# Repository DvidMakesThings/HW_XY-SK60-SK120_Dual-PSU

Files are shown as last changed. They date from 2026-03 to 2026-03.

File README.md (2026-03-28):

# XY-SK60 / XY-SK120 Dual PSU Controller

**Open-source remote control and automation system for dual Sinilink XY-SK60/SK120 buck-boost power supplies — built around a Luckfox RV1106 SoC in a 10-inch 1U rack enclosure.**




---

## Table of Contents

- [Project Overview](#project-overview)
- [Hardware](#hardware)
  - [PSU Modules](#psu-modules-sinilink-xy-sk60--xy-sk120)
  - [Controller: Luckfox Pico Plus](#controller-luckfox-pico-plus-rv1106)
  - [Serial Interface & Wiring](#serial-interface--wiring)
  - [Enclosure](#enclosure)
  - [Bill of Materials](#bill-of-materials)
- [Software Architecture](#software-architecture)
- [Web UI](#web-ui)
  - [Outputs](#outputs)
  - [Protection](#protection)
  - [Settings](#settings)
  - [Sweep](#sweep)
  - [Datalogger](#datalogger)
  - [API Docs / SNMP Docs / System Info](#api-docs--snmp-docs--system-info)
- [REST API](#rest-api)
- [SNMP Agent](#snmp-agent)
- [Deployment](#deployment)
  - [Prerequisites](#prerequisites)
  - [Windows Deployment](#windows-deployment-pscp--plink)
  - [Linux / macOS Deployment](#linux--macos-deployment)
  - [Manual Deployment](#manual-deployment)
  - [Service Management](#service-management)
- [Configuration](#configuration)
- [Typical Use Cases](#typical-use-cases)
- [License](#license)
- [Contact](#contact)
- [Contributing](#contributing)

---

## Project Overview

This project turns two off-the-shelf Sinilink XY-SK60 or XY-SK120 buck-boost modules into a fully networked, rack-mounted lab power system. A Luckfox Pico Plus SBC (RV1106 SoC, running Linux) sits between the PSUs and the network, communicating with each PSU over Modbus RTU via dedicated UARTs and exposing a feature-rich control interface.

**What you get:**

| Capability | Detail |
|---|---|
| Web dashboard | Real-time V/I/P telemetry, output control, protection config, settings |
| Voltage sweep | Timed voltage sequences — define waypoints, upload, start/stop |
| Datalogger | Per-channel V/I/P time-series, live graph, CSV export |
| REST API | Full JSON API for scripting and automation |
| SNMP agent | SNMPv2c for integration with Zabbix, Nagios, LibreNMS, etc. |
| 10-inch 1U rack | 3D-printable enclosure, all files included |

---

## Hardware

### PSU Modules: Sinilink XY-SK60 / XY-SK120

The Sinilink XY-SK60 and XY-SK120 are synchronous buck-boost DC-DC converter modules with an onboard microcontroller, LCD display, and a serial (Modbus RTU) control port.

| Parameter | XY-SK60 | XY-SK120 |
|---|---|---|
| Input voltage | 8 – 60 V DC | 8 – 60 V DC |
| Output voltage | 1 – 60 V DC | 1 – 60 V DC |
| Max output current | 6 A | 12 A |
| Max output power | 60 W | 120 W |
| Conversion efficiency | up to 98% | up to 98% |
| Display | colour LCD | colour LCD |
| Serial interface | UART 115200 8N1 | UART 115200 8N1 |
| Control protocol | Modbus RTU (slave addr 1) | Modbus RTU (slave addr 1) |

Both variants expose identical register maps and are fully interchangeable in this system. The modules have a 6-pin serial header exposing TX, RX, GND and 3.3 V.

The `doc/` folder contains the official SK60/SK120 user guide PDF with the full register map.

### Controller: Luckfox Pico Plus (RV1106)

The controller runs on a [Luckfox Pico Plus](https://www.luckfox.com/), a credit-card-sized Linux SBC based on the Rockchip RV1106 SoC.

| Parameter | Value |
|---|---|
| SoC | Rockchip RV1106 (ARM Cortex-A7, 1.2 GHz) |
| RAM | 64 MB DDR2 |
| Storage | 8 MB SPI NOR flash (runs Linux from flash) |
| OS | BusyBox-based Linux |
| Network | 100 Mbit Ethernet |
| UARTs used | ttyS3 (PSU-B), ttyS4 (PSU-A) |

Any Linux SBC with two free UARTs and Ethernet will work as a drop-in replacement (Raspberry Pi Zero 2, Orange Pi Zero, etc.). Only the UART device paths in `config.json` need adjustment.

### Serial Interface & Wiring

Each PSU communicates at **115200 baud, 8N1, Modbus RTU** on a dedicated UART. The controller reads all live registers in a single burst (30 registers from address 0x00) and writes individual registers for commands.

```
PSU-A  ──TX──►  RV1106 ttyS4 RX
       ◄─RX──   RV1106 ttyS4 TX
       ──GND─   GND
       ──5V─    5 V (optional, but the PSU exposes an 5V supply pin on the UART header, can be used for powering the SoC)

PSU-B  ──TX──►  RV1106 ttyS3 RX
       ◄─RX──   RV1106 ttyS3 TX
       ──GND─   GND
```

The UARTs operate at 3.3 V logic. No level shifting is needed between the Luckfox and the PSU serial headers. Each UART is a point-to-point connection (no RS-485 bus required).

**Register address map (key registers):**

| Address | Name | Scale | Access |
|---|---|---|---|
| 0x0000 | V_SET — voltage setpoint | ÷ 100 → V | R/W |
| 0x0001 | I_SET — current limit | ÷ 1000 → A | R/W |
| 0x0002 | VOUT — output voltage | ÷ 100 → V | RO |
| 0x0003 | IOUT — output current | ÷ 1000 → A | RO |
| 0x0004 | POWER — output power | ÷ 100 → W | RO |
| 0x0005 | UIN — input voltage | ÷ 100 → V | RO |
| 0x000D | T_IN — internal temp | ÷ 10 → °C | RO |
| 0x0012 | ONOFF — output enable | 1=ON, 0=OFF | R/W |
| 0x0011 | CVCC — CV/CC mode | 0=CV, 1=CC | RO |
| 0x0010 | PROTECT — protection flags | bitmask | RO |

The full register map is in `src/psu_controller/modbus_psu.py` and the PSU user guide.

### Enclosure

The system is built into a **10-inch, 1U rack enclosure** that is fully 3D printable.

<p align="center">
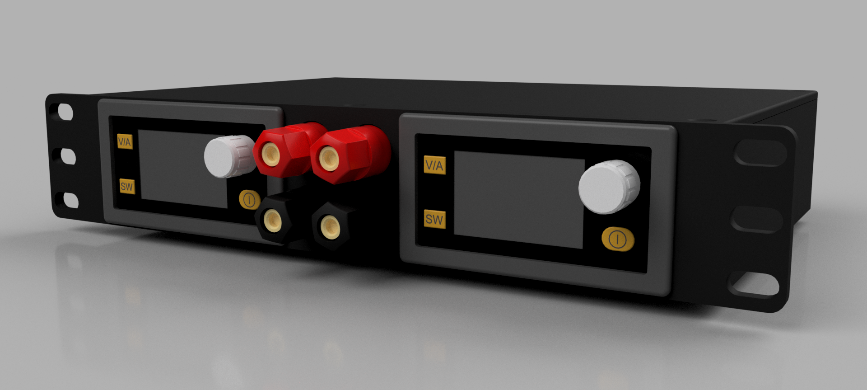
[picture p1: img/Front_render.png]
Front Render
  
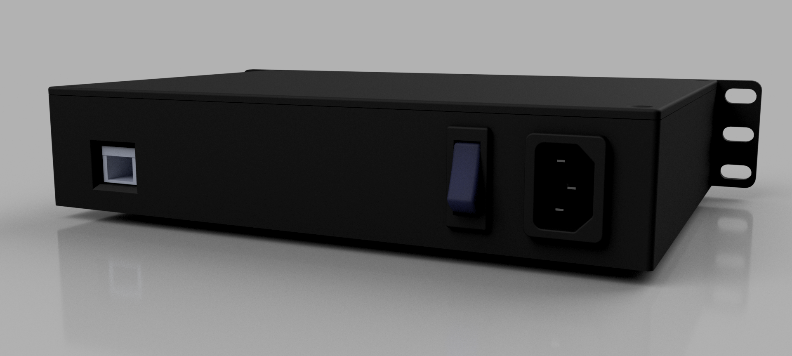
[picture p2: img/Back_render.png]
Back Render
  
</p>

<p align="center">
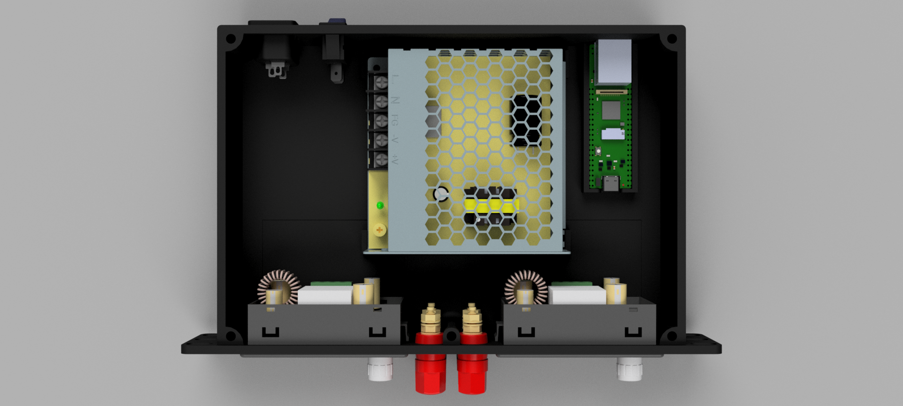
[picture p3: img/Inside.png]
Internal Layout
  
</p>

- **Form factor:** 1U × 10-inch rack (compatible with standard 10-inch patch panels and mini-racks)
- **3D files:** `3D files/` contains STEP models for the body, lid, and full assembly with internal components
- **Fastening:** designed for M3 hardware
- Both PSU modules mount inside the body, with the Luckfox mounted to the lid or rear panel

### Bill of Materials

Parts used in the reference build. Prices are approximate at time of purchase.

| Qty | Part | Unit Price | Link |
|---|---|---|---|
| 1 | Luckfox Pico Plus (RV1103) — SBC / controller | ~$20 | [luckfox.com](https://www.luckfox.com/EN-Luckfox-Pico-Plus) |
| 2 | Sinilink XY-SK120 60V/12A buck-boost module | ~$26 | [amazon.com](https://www.amazon.com/Converter-Voltage-Adjustable-Supply-Display/dp/B0D9H3Z637?th=1) |
| 1 | Mean Well LRS-75-12 — 12 V / 6 A PSU (logic power) | ~$14 | [amazon.com](https://a.co/d/09D2P6Ac) |
| 4 | Banana jack panel mounts (binding posts) | ~$2 each | [amazon.de](https://www.amazon.de/dp/B09D725WSX) |
| 1 | IEC 320 C14 panel-mount power inlet (4-pack) | ~$7/4 | [amazon.com](https://a.co/d/0aa4EqbB) |
| 1 | Snap-in rocker switch (5-pack) | ~$7/5 | [amazon.com](https://a.co/d/00OINL1y) |
| — | 14 AWG mains and DC wiring | — | — |

**Total reference build cost: ~$95** (excluding 3D printing filament, M3 hardware, and connectors)

> The XY-SK60 (6 A / 60 W) is a drop-in substitute for the XY-SK120 at lower cost (~$18) if you don't need 12 A output. Both are fully supported by this firmware.

---

## Software Architecture

The controller software runs as a single Python process under a BusyBox init.d service (`/etc/init.d/S99psucontroller`). All files install to `/opt/psu_controller/`.

```
psu_controller.py          ← main entry point, wires everything together
│
├── modbus_psu.py           ← Modbus RTU driver (one instance per PSU)
│    ├── read_all()          — bulk-reads 30 registers in one transaction
│    ├── set_voltage(v)      — writes REG_V_SET
│    ├── set_current(i)      — writes REG_I_SET
│    ├── set_output(on)      — writes REG_ONOFF
│    └── get_readings_cached() — returns last polled values (thread-safe)
│
├── web_server.py           ← single-threaded HTTP server (BaseHTTPRequestHandler)
│    ├── GET  /              — serves index.html
│    ├── GET  /app.js etc    — serves static web assets
│    ├── GET  /api/...       — JSON API read endpoints
│    └── POST /api/...       — JSON API command endpoints
│
├── sweep_manager.py        ← per-PSU timed voltage/output sequencer
│    ├── set_program()       — validates and stores waypoint list
│    ├── start()             — launches sweep thread
│    ├── stop()              — signals thread to stop
│    └── _run()              — 50 ms loop; applies waypoint actions on step change
│
├── datalogger.py           ← per-PSU time-series ring buffer logger
│    ├── start(interval_ms)  — launches logging thread
│    ├── stop()              — signals thread to stop
│    ├── get_data()          — returns samples as list of {t, v, i, p} dicts
│    └── get_csv()           — returns CSV string (time_ms, voltage_V, current_A, power_W)
│
├── snmp_agent.py           ← SNMPv2c agent (raw UDP socket, port 161)
│    └── exposes 28 OIDs per PSU channel (reads, settings, protection thresholds)
│
├── config.json             ← serial ports, baud rates, web/SNMP bind addresses
│
└── web/
     ├── index.html          ← single-page application shell
     ├── app.js              ← all UI logic (vanilla JS, no framework)
     └── style.css           ← all styles (CSS variables, grid, dark theme)
```

**Threading model:**
- Main thread: starts all services, then blocks
- Web server thread: one persistent thread handles all HTTP requests serially
- SNMP thread: one persistent thread handles all UDP datagrams serially
- PSU polling thread (×2): each `ModbusPSU` instance runs its own background thread that continuously polls registers and caches the result
- Sweep thread (×2, on demand): one thread per PSU when a sweep is running
- Datalogger thread (×2, on demand): one thread per PSU when logging is active

All shared state is protected by `threading.Lock()`. The web server never touches serial hardware directly — it reads from caches and dispatches commands to the PSU driver.

---

## Web UI

Access the web interface at `http://[DEVICE_IP]:8080/`. The UI is a single-page application with no external dependencies. All pages share a persistent sidebar for navigation and datalogger status.

### Outputs

<p align="center">
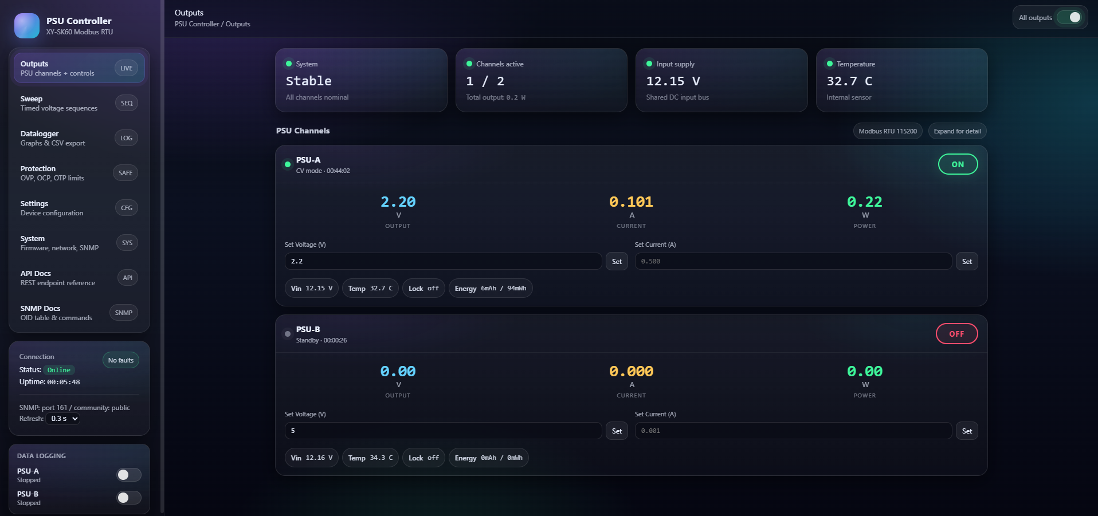
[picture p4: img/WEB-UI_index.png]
Web UI Outputs
  
</p>

The default page shows both PSU channels side by side (or stacked on narrow displays). For each channel:

- **Live readings** (refreshed every 300 ms): output voltage, current, power — displayed in large, colour-coded digits
- **Output toggle button**: green ON / grey OFF; reflects actual hardware state
- **CV/CC indicator**: shows whether the PSU is operating in constant-voltage or constant-current mode
- **Uptime counter**: accumulated output-on time (H:MM:SS)
- **Set Voltage / Set Current inputs**: type a value and press Set (or Enter). Inputs use `type="text"` to preserve partial input during polling; the placeholder shows the current setpoint. Inputs are fully stable during refresh — focus, cursor position, and text selection are never disturbed by background polling.
- **Info chips**: input voltage, internal temperature, key lock state, accumulated energy (mAh / mWh), and protection alert if active

### Protection

Per-channel protection threshold configuration:

| Setting | Description |
|---|---|
| OVP | Over-Voltage Protection — shuts output if Vout exceeds threshold |
| OCP | Over-Current Protection — shuts output if Iout exceeds threshold |
| OPP | Over-Power Protection — shuts output if power exceeds threshold |
| OTP | Over-Temperature Protection — shuts output if temp exceeds threshold |
| LVP | Low-Voltage Protection — shuts output if Vin drops below threshold |
| OHP | Over-Hours Protection — shuts output after a set run time (H:MM) |
| OAH | Over Amp-Hours — shuts output after accumulated charge (mAh) |
| OWH | Over Watt-Hours — shuts output after accumulated energy (mWh) |

### Settings

Per-channel device settings: backlight level (0–5), auto-sleep timeout, key lock, beeper, temperature unit (°C/°F), MPPT solar mode, constant-power mode, battery-full cutoff current, preset data group selection, power-on output state, temperature sensor calibration offsets, and factory reset.

### Sweep

The sweep function lets you define and execute a timed voltage/output sequence on each PSU independently. This is useful for automated test sequences, burn-in profiles, ramp testing, and similar applications.

<p align="center">
  <img src="img\WEB-UI_Sweep.png" alt="Sweep" "/>
</p>

**How waypoints work:**

Each waypoint specifies an **elapsed time from sweep start** and one or both of:
- **Voltage** — set the output voltage to this value at this timestamp
- **Output state** — turn output ON or OFF at this timestamp

Waypoints are sorted by time and executed in order. The sweep runs at 50 ms resolution. When the last waypoint time is reached, the sweep ends automatically and the PSU holds its last-programmed voltage.

**Example sequence** (ramp + test + off):

| Time | Action |
|---|---|
| 0 ms | Enable output, set 0.0 V |
| 500 ms | Set 5.0 V |
| 2000 ms | Set 12.0 V |
| 5000 ms | Set 12.0 V (hold) |
| 8000 ms | Set 5.0 V |
| 10000 ms | Disable output |

**UI workflow:**
1. Click `+ Voltage` or `+ Enable Output` / `+ Disable Output` to add waypoints
2. Set the elapsed time (ms) for each waypoint
3. Press **Save Program** — uploads the program to the controller
4. Press **Start** to begin execution; **Stop** to abort at any time
5. Status shows elapsed time and current step while running

Both PSUs maintain independent programs. Sweeps on both PSUs can run simultaneously.

### Datalogger

The datalogger records voltage, current, and power samples from each PSU at a configurable interval (minimum 100 ms, default 500 ms). Up to 10,000 samples are stored in memory per channel in a ring buffer (oldest are dropped when full).

<p align="center">
  <img src="img\WEB-UI_Datalogger.png" alt="Datalogger" "/>
</p>

**Enabling logging:**
- Toggle the **LOG** switch in the sidebar for each PSU channel
- The switch can also be controlled via the REST API

**Datalogger page:**
- Two-column layout with PSU-A on the left, PSU-B on the right
- Each column has two canvas charts: voltage (cyan) and current (yellow)
- Y axes auto-scale to the data range
- X axis shows absolute elapsed time from first sample

**Interactive hover:**
Move the mouse over any chart. When the cursor is within 20 px of the plotted curve, the chart shows:
- A dashed vertical crosshair at the nearest sample
- A filled dot on the curve
- A tooltip with the exact value and elapsed time (e.g. `3.284V  @1.23s`)

**CSV export:**
- Click **Download CSV** to download the log for each PSU
- Or `GET /api/datalog/{id}/csv` via the API
- Columns: `time_ms, voltage_V, current_A, power_W`
- Compatible with Excel, pandas, MATLAB, gnuplot, etc.

### API Docs / SNMP Docs / System Info

The last three sidebar items are reference panels built into the UI:

- **API Docs** — full REST endpoint reference with live base URL, payload examples, and curl commands (the device IP is substituted automatically)
- **SNMP Docs** — full OID table (28 columns, 2 rows), type/scale/access info, and a complete set of copy-pasteable snmpget/snmpset commands with the device IP pre-filled
- **System Info** — firmware version, serial port assignments, SNMP configuration, and network details

---

## REST API

Full reference: [API.md](API.md)

**Base URL:** `http://[DEVICE_IP]:8080/api/`

All GET endpoints return JSON. All POST endpoints accept a JSON body and return `{"success": true}` or `{"success": false, "error": "..."}`. CORS is open (`*`), so the API can be called from browser scripts on any origin.

**Quick reference:**

| Method | Endpoint | Purpose |
|---|---|---|
| GET | `/api/status` | All PSU data in one call |
| GET | `/api/psu/{id}/readings` | Live V/I/P/Vin/Temp readings |
| POST | `/api/psu/{id}/output` | Enable/disable output |
| POST | `/api/psu/{id}/voltage` | Set voltage setpoint |
| POST | `/api/psu/{id}/current` | Set current limit |
| GET | `/api/sweep/{id}` | Sweep program and run status |
| POST | `/api/sweep/{id}/set` | Upload a sweep program |
| POST | `/api/sweep/{id}/start` | Start sweep execution |
| POST | `/api/sweep/{id}/stop` | Stop sweep |
| GET | `/api/datalog/{id}` | Logged samples (JSON) |
| GET | `/api/datalog/{id}/csv` | Logged samples (CSV download) |
| POST | `/api/datalog/{id}/start` | Start logging |
| POST | `/api/datalog/{id}/stop` | Stop logging |
| POST | `/api/datalog/{id}/clear` | Clear buffer |

PSU IDs are `a` and `b`.

**Scripting example (bash):**
```bash
BASE=http://192.168.0.190:8080/api
# Ramp PSU-A to 12 V, enable output, log for 10 s, download CSV
curl -sX POST -H 'Content-Type:application/json' -d '{"voltage":12.0}' $BASE/psu/a/voltage
curl -sX POST -H 'Content-Type:application/json' -d '{"enabled":true}'  $BASE/psu/a/output
curl -sX POST -H 'Content-Type:application/json' -d '{"interval_ms":200}' $BASE/datalog/a/start
sleep 10
curl -sX POST $BASE/datalog/a/stop
curl -o psu_a.csv $BASE/datalog/a/csv
```

**Python example:**
```python
import requests, time

BASE = 'http://192.168.0.190:8080/api'

# Set voltage and enable output
requests.post(f'{BASE}/psu/a/voltage', json={'voltage': 5.0})
requests.post(f'{BASE}/psu/a/output',  json={'enabled': True})

# Poll readings
r = requests.get(f'{BASE}/psu/a/readings').json()
print(f"Vout={r['v_out']:.3f} V  Iout={r['i_out']:.3f} A  P={r['power']:.2f} W")

# Upload and run a sweep
points = [
    {'time_ms': 0,     'voltage': 0.0},
    {'time_ms': 1000,  'voltage': 5.0},
    {'time_ms': 3000,  'voltage': 12.0},
    {'time_ms': 6000,  'voltage': 3.3},
    {'time_ms': 8000,  'output': False},
]
requests.post(f'{BASE}/sweep/a/set',   json={'points': points})
requests.post(f'{BASE}/sweep/a/start', json={})
```

---

## SNMP Agent

Full reference: [SNMP.md](SNMP.md)

The controller runs a built-in SNMPv2c agent on **UDP port 161**. It exposes 28 OID columns per PSU channel (56 leaf OIDs total) covering all live readings, settings, and protection thresholds. Both GET and SET are supported; writable OIDs accept raw integer values scaled by the documented factor.

**Configuration:**
- Read community: `public`
- Write community: `private`
- Base OID: `1.3.6.1.4.1.99999.1`
- Rows: 1 = PSU-A, 2 = PSU-B
- Supports: GET, GETNEXT, GETBULK, SET

**Quick examples:**
```bash
# Read output voltage of PSU-A (raw x100, e.g. 1250 = 12.50 V)
snmpget -v2c -c public 192.168.0.190 1.3.6.1.4.1.99999.1.2.1.5.1

# Set PSU-B voltage to 5.00 V
snmpset -v2c -c private 192.168.0.190 1.3.6.1.4.1.99999.1.2.1.3.2 i 500

# Walk all parameters for all channels
snmpwalk -v2c -c public 192.168.0.190 1.3.6.1.4.1.99999.1.2

# Bulk-get all 28 OID columns for PSU-A in one packet
snmpbulkget -v2c -c public -Cr28 192.168.0.190 1.3.6.1.4.1.99999.1.2.1.0.1
```

For Zabbix integration, add the device as an SNMP host with community `public` and create items using the OIDs from [SNMP.md](SNMP.md). The raw integer values require the divisor applied in the Zabbix preprocessing step (multiply by 0.01 for x100-scaled voltage, 0.001 for x1000-scaled current, etc.).

---

## Deployment

### Prerequisites

The PSU modules and controller must be physically assembled and wired (see [Serial Interface & Wiring](#serial-interface--wiring)). The Luckfox device must be on the network and reachable by SSH.

Default device credentials: `root` / `luckfox`

### Windows Deployment (pscp + plink)

Requires [PuTTY tools](https://www.chiark.greenend.org.uk/~sgtatham/putty/latest.html) (`pscp.exe`, `plink.exe`) in your PATH.

```cmd
# Auto-detect device and deploy with default password
setup_psu_server.bat

# Specify IP
setup_psu_server.bat 192.168.0.190

# Specify IP and custom password
setup_psu_server.bat 192.168.0.190 mypassword
```

The script:
1. Uploads all files in `src/psu_controller/` to `/opt/psu_controller/` on the device
2. Installs the init.d service (`/etc/init.d/S99psucontroller`)
3. Starts the service

### Linux / macOS Deployment

Requires `sshpass` and `scp`.

```bash
# Install sshpass if needed
sudo apt install sshpass   # Debian/Ubuntu
brew install hudochenkov/sshpass/sshpass  # macOS

# Deploy
bash setup_psu_server.sh
bash setup_psu_server.sh 192.168.0.190
bash setup_psu_server.sh 192.168.0.190 mypassword
```

### Manual Deployment

If you prefer to deploy manually or from a CI pipeline:

```bash
DEVICE=192.168.0.190
PASS=luckfox

# Upload Python files
for f in psu_controller.py modbus_psu.py web_server.py snmp_agent.py \
          sweep_manager.py datalogger.py config.json; do
    sshpass -p $PASS scp src/psu_controller/$f root@$DEVICE:/opt/psu_controller/$f
done

# Upload web assets
for f in index.html style.css app.js; do
    sshpass -p $PASS scp src/psu_controller/web/$f root@$DEVICE:/opt/psu_controller/web/$f
done

# Upload service script
sshpass -p $PASS scp src/psu_controller/S99psucontroller root@$DEVICE:/etc/init.d/
sshpass -p $PASS ssh root@$DEVICE "chmod +x /etc/init.d/S99psucontroller"

# Start service
sshpass -p $PASS ssh root@$DEVICE "sh /etc/init.d/S99psucontroller restart"
```

### Service Management

The controller runs as a BusyBox init.d service (the Luckfox does **not** use systemd).

```bash
# Restart service (e.g. after a config change or file upload)
plink -batch -pw luckfox root@192.168.0.190 "sh /etc/init.d/S99psucontroller restart"

# Stop / start
plink -batch -pw luckfox root@192.168.0.190 "sh /etc/init.d/S99psucontroller stop"
plink -batch -pw luckfox root@192.168.0.190 "sh /etc/init.d/S99psucontroller start"

# View live log
plink -batch -pw luckfox root@192.168.0.190 "tail -f /var/log/psu_controller.log"
```

The web server and SNMP agent start automatically on boot. No manual start is needed after initial deployment.

---

## Configuration

`src/psu_controller/config.json` is the single configuration file. It is copied to `/opt/psu_controller/config.json` on the device.

```json
{
    "psus": {
        "a": {
            "port": "/dev/ttyS4",
            "name": "PSU-A",
            "baudrate": 115200,
            "address": 1
        },
        "b": {
            "port": "/dev/ttyS3",
            "name": "PSU-B",
            "baudrate": 115200,
            "address": 1
        }
    },
    "web": {
        "host": "0.0.0.0",
        "port": 8080
    },
    "snmp": {
        "host": "0.0.0.0",
        "port": 161,
        "community": "public",
        "write_community": "private"
    }
}
```

**Key fields:**

| Field | Description |
|---|---|
| `psus.{id}.port` | Serial device node for this PSU |
| `psus.{id}.address` | Modbus slave address (default 1, set on PSU) |
| `psus.{id}.baudrate` | Must match PSU baud setting (default 115200) |
| `psus.{id}.name` | Display name shown in UI |
| `web.port` | HTTP server port (default 8080) |
| `snmp.community` | Read community string |
| `snmp.write_community` | Write community string |

To add a third PSU (if using a controller with a third UART), add a `"c"` key under `psus` with the appropriate port.

After editing `config.json`, upload it and restart the service.

---

## Typical Use Cases

**Automated test bench** — Upload a sweep program via the API before each test run. Start the sweep from a test script, poll `/api/psu/{id}/readings` to measure DUT response, stop and download the log as CSV when done. Fully scriptable with any language that can make HTTP requests.

**Battery characterisation** — Enable the datalogger at 100–200 ms intervals while running a discharge sweep. Export the CSV and plot V/I vs. time in Python/MATLAB to extract capacity, internal resistance, and discharge curves.

**Solar MPPT lab testing** — Use MPPT mode on one PSU to simulate a solar panel source, and the other PSU in CC mode as a programmable load. Run both sweeps simultaneously and log both channels to correlate the waveforms.

**Zabbix / Nagios monitoring** — Add the device as an SNMP v2c host. Monitor output voltage, current, temperature, and protection status. Alert on protection events (psuProtectStatus != 0) or overcurrent conditions.

**Burn-in testing** — Define a long-duration sweep with output on/off cycles and varying voltages. The sweep runs unattended and ends automatically; no poll loop required.

---

## License
### Software Components
This project's software is licensed under the **GNU Affero General Public License v3.0 (AGPL-3.0)**.
See the [Software License](LICENSE-AGPL) file for details.

#### What AGPL-3.0 means:

- ✅ **You can** freely use, modify, and distribute this software
- ✅ **You can** use this project for personal, educational, or internal purposes
- ✅ **You can** contribute improvements back to this project

- ⚠️ **You must** share any modifications you make if you distribute the software
- ⚠️ **You must** release the source code if you run a modified version on a server that others interact with
- ⚠️ **You must** keep all copyright notices intact

- ❌ **You cannot** incorporate this code into proprietary software without sharing your source code
- ❌ **You cannot** use this project in a commercial product without either complying with AGPL or obtaining a different license

### Hardware Components
Hardware designs, schematics, and related documentation are licensed under the **Creative Commons Attribution-NonCommercial-ShareAlike 4.0 International License (CC BY-NC-SA 4.0)**. See the [Hardware License](LICENSE-CC-BY-NC-SA) file for details.

#### What CC BY-NC-SA 4.0 means:

- ✅ **You can** study, modify, and distribute the hardware designs
- ✅ **You can** create derivative works for personal, educational, or non-commercial use
- ✅ **You can** build this project for your own personal use

- ⚠️ **You must** give appropriate credit and indicate if changes were made
- ⚠️ **You must** share any modifications under the same license terms
- ⚠️ **You must** include the original license and copyright notices

- ❌ **You cannot** use the designs for commercial purposes without explicit permission
- ❌ **You cannot** manufacture and sell products based on these designs without a commercial license
- ❌ **You cannot** create closed-source derivatives for commercial purposes
- ❌ **You cannot** use the designer's trademarks without permission

### Commercial & Enterprise Use

Commercial use of this project is prohibited without obtaining a separate commercial license. If you are interested in:

- Manufacturing and selling products based on these designs
- Incorporating these designs into commercial products
- Any other commercial applications

Please contact me through any of the channels listed in the [Contact](#contact) section to discuss commercial licensing arrangements. Commercial licenses are available with reasonable terms to support ongoing development.

## Contact

For questions or feedback:
- **Email:** [dvidmakesthings@gmail.com](mailto:dvidmakesthings@gmail.com)
- **GitHub:** [DvidMakesThings](https://github.com/DvidMakesThings)

## Contributing

Contributions are welcome! As this is an early-stage project, please reach out before 
making substantial changes:

1. Fork the repository
2. Create a feature branch (`git checkout -b feature/concept`)
3. Commit your changes (`git commit -m 'Add concept'`)
4. Push to the branch (`git push origin feature/concept`)
5. Open a Pull Request with a detailed description

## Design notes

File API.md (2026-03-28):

# REST API Reference

This document describes the full REST API exposed by the Dual PSU Controller.

**Base URL:** `http://[DEVICE_IP]:8080/api/`
**PSU IDs:** `a` (PSU-A) and `b` (PSU-B)
**Content-Type:** All POST requests must include `Content-Type: application/json`
**CORS:** `Access-Control-Allow-Origin: *` — the API is accessible from any browser origin

---

## Response Format

**GET endpoints** return a JSON object with the requested data.

**POST endpoints** always return:
```json
{ "success": true }
```
or on failure:
```json
{ "success": false, "error": "Human-readable error message" }
```

---

## Status Endpoints

### `GET /api/status`
Full status object for all connected PSUs. Combines readings, settings, and protection data in a single call. Useful for dashboards that need everything at once.

**Response:**
```json
{
  "a": {
    "name": "PSU-A",
    "v_set": 12.50,
    "i_set": 2.000,
    "v_out": 12.48,
    "i_out": 0.312,
    "power": 3.89,
    "v_in": 24.10,
    "ah": 142,
    "wh": 1730,
    "out_hours": 0,
    "out_mins": 12,
    "out_secs": 34,
    "temp_int": 31.8,
    "temp_ext": -1.0,
    "lock": 0,
    "protect": 0,
    "cvcc": 0,
    "output_on": true,
    "backlight": 3,
    "sleep": 0,
    "beeper": 1,
    "f_c": 0,
    "model": 6000,
    "firmware": 130,
    "protection": {
      "ovp": 62.0, "ocp": 6.100, "opp": 360.0,
      "otp": 80.0, "lvp": 10.0,
      "ohp_h": 0, "ohp_m": 0, "oah": 0, "owh": 0,
      "power_on_init": false
    }
  },
  "b": { "..." }
}
```

### `GET /api/psu/{id}`
Full status for a single PSU. Same structure as one entry in `/api/status`.

```bash
curl http://192.168.0.190:8080/api/psu/a
```

### `GET /api/psu/{id}/readings`
Live measurements only. Polled at the PSU background thread rate (~200 ms cycle).

**Response:**
```json
{
  "v_out": 12.48,
  "i_out": 0.312,
  "power": 3.89,
  "v_in": 24.10,
  "v_set": 12.50,
  "i_set": 2.000,
  "ah": 142,
  "wh": 1730,
  "out_hours": 0,
  "out_mins": 12,
  "out_secs": 34,
  "temp_int": 31.8,
  "temp_ext": -1.0,
  "cvcc": 0,
  "output_on": true,
  "protect": 0
}
```

`cvcc`: `0` = constant-voltage mode, `1` = constant-current mode.
`protect`: protection status register bitmask; `0` = no active protection event.
`temp_ext`: `-1.0` indicates no external sensor connected.

```bash
curl http://192.168.0.190:8080/api/psu/a/readings
```

### `GET /api/psu/{id}/settings`
Device configuration settings.

**Response:**
```json
{
  "backlight": 3,
  "sleep": 0,
  "lock": 0,
  "beeper": 1,
  "f_c": 0,
  "model": 6000,
  "firmware": 130,
  "slave_addr": 1,
  "baudrate": 6
}
```

### `GET /api/psu/{id}/protection`
Protection thresholds and accumulated energy limits.

**Response:**
```json
{
  "ovp": 62.0,
  "ocp": 6.100,
  "opp": 360.0,
  "otp": 80.0,
  "lvp": 10.0,
  "ohp_h": 0,
  "ohp_m": 0,
  "oah": 0,
  "owh": 0,
  "power_on_init": false
}
```

### `GET /api/snmp`
SNMP agent configuration (community strings, port, base OID).

```bash
curl http://192.168.0.190:8080/api/snmp
```

---

## Control Endpoints

### `POST /api/psu/{id}/output`
Enable or disable the PSU output.

```json
{ "enabled": true }
```
```bash
curl -X POST -H 'Content-Type: application/json' \
     -d '{"enabled":true}' \
     http://192.168.0.190:8080/api/psu/a/output
```

### `POST /api/psu/{id}/voltage`
Set the output voltage setpoint in volts. The PSU enforces its own OVP limit.

```json
{ "voltage": 12.50 }
```
```bash
curl -X POST -H 'Content-Type: application/json' \
     -d '{"voltage":12.5}' \
     http://192.168.0.190:8080/api/psu/a/voltage
```

### `POST /api/psu/{id}/current`
Set the output current limit in amps.

```json
{ "current": 2.000 }
```

### `POST /api/psu/{id}/lock`
Lock or unlock the front panel keys (prevents physical button presses from changing settings).

```json
{ "locked": true }
```

### `POST /api/psu/{id}/backlight`
Set the LCD backlight level. `0` = off, `5` = maximum brightness.

```json
{ "level": 3 }
```

### `POST /api/psu/{id}/sleep`
Auto-sleep timeout in minutes. `0` disables auto-sleep.

```json
{ "minutes": 30 }
```

### `POST /api/psu/{id}/beeper`
Enable or disable the key press beeper.

```json
{ "enabled": false }
```

### `POST /api/psu/{id}/temp_unit`
Switch the temperature display between Celsius and Fahrenheit.

```json
{ "fahrenheit": true }
```

### `POST /api/psu/{id}/mppt`
Enable MPPT (Maximum Power Point Tracking) solar mode and/or set the input voltage threshold. In MPPT mode, the PSU regulates its input current to keep input voltage at or above the threshold, preventing source collapse.

```json
{ "enabled": true, "threshold": 18.0 }
```

### `POST /api/psu/{id}/cp`
Enable constant-power mode and/or set the power target in watts. The PSU adjusts current to maintain the specified output power.

```json
{ "enabled": true, "power": 25.0 }
```

### `POST /api/psu/{id}/btf`
Battery-full cutoff current threshold in amps. The output turns off automatically when output current drops below this value. Useful for CC/CV battery charging.

```json
{ "current": 0.100 }
```

### `POST /api/psu/{id}/data_group`
Select a preset data group (0–9). Each group stores independent V/I setpoints on the PSU.

```json
{ "group": 3 }
```

### `POST /api/psu/{id}/power_on_init`
Set whether the output is automatically enabled on PSU power-up.

```json
{ "output_on": true }
```

---

## Protection Endpoints

### `POST /api/psu/{id}/ovp`
Over-Voltage Protection threshold in volts. Output shuts off if Vout exceeds this value.

```json
{ "voltage": 62.0 }
```

### `POST /api/psu/{id}/ocp`
Over-Current Protection threshold in amps. Output shuts off if Iout exceeds this value.

```json
{ "current": 6.100 }
```

### `POST /api/psu/{id}/opp`
Over-Power Protection threshold in watts.

```json
{ "power": 360.0 }
```

### `POST /api/psu/{id}/otp`
Over-Temperature Protection threshold in °C. Output shuts off if the internal sensor exceeds this temperature.

```json
{ "temperature": 80.0 }
```

### `POST /api/psu/{id}/lvp`
Low-Voltage Protection threshold on the DC input (volts). Output shuts off if the input bus voltage drops below this level. Useful for protecting battery sources from deep discharge.

```json
{ "voltage": 10.0 }
```

### `POST /api/psu/{id}/ohp`
Over-Hours Protection. Output shuts off after this cumulative run time.

```json
{ "hours": 8, "minutes": 30 }
```

### `POST /api/psu/{id}/oah`
Over Amp-Hours Protection threshold in mAh. Output shuts off after this accumulated charge has been delivered.

```json
{ "mah": 5000 }
```

### `POST /api/psu/{id}/owh`
Over Watt-Hours Protection threshold in mWh. Output shuts off after this accumulated energy has been delivered.

```json
{ "mwh": 50000 }
```

### `POST /api/psu/{id}/temp_cal`
Apply a calibration offset in °C to the internal and/or external temperature sensors. Positive values increase the reported temperature; negative values decrease it.

```json
{ "internal": 0.5, "external": -1.2 }
```

### `POST /api/psu/{id}/factory_reset`
Reset all settings to factory defaults. This cannot be undone.

```json
{}
```
```bash
curl -X POST http://192.168.0.190:8080/api/psu/a/factory_reset
```

---

## Sweep Endpoints

The sweep system executes a timed sequence of voltage and/or output-state changes on a PSU. Each waypoint specifies an elapsed time (ms from sweep start) and at least one action (`voltage` and/or `output`). Waypoints are sorted by `time_ms` server-side and executed at 50 ms resolution. The sweep ends automatically after the last waypoint.

### `GET /api/sweep`
Sweep program and execution status for all PSUs.

**Response:**
```json
{
  "a": {
    "program": [
      { "time_ms": 0,     "voltage": 0.0 },
      { "time_ms": 500,   "output": true  },
      { "time_ms": 1000,  "voltage": 5.0  },
      { "time_ms": 5000,  "voltage": 12.0 },
      { "time_ms": 10000, "output": false }
    ],
    "status": {
      "running": true,
      "elapsed_ms": 3240,
      "current_step": 2
    }
  },
  "b": { "..." }
}
```

`current_step`: index (0-based) of the last applied waypoint. `-1` before any waypoint has been applied.

### `GET /api/sweep/{id}`
Sweep program and status for a single PSU.

```bash
curl http://192.168.0.190:8080/api/sweep/a
```

### `POST /api/sweep/{id}/set`
Upload a sweep program. The existing program is replaced. You can upload a new program while the PSU is idle; the sweep does not start automatically.

Each waypoint must have `time_ms` and at least one of `voltage` (float, volts) or `output` (bool). A single waypoint may contain both.

```json
{
  "points": [
    { "time_ms": 0,     "voltage": 0.0,  "output": true  },
    { "time_ms": 1000,  "voltage": 5.0                   },
    { "time_ms": 3000,  "voltage": 12.0                  },
    { "time_ms": 6000,  "voltage": 3.3                   },
    { "time_ms": 8000,  "output": false                  }
  ]
}
```

```bash
curl -X POST -H 'Content-Type: application/json' \
     -d '{"points":[{"time_ms":0,"voltage":0},{"time_ms":5000,"voltage":12.0}]}' \
     http://192.168.0.190:8080/api/sweep/a/set
```

### `POST /api/sweep/{id}/start`
Start sweep execution. Returns an error if no program is defined or a sweep is already running.

```json
{}
```
```bash
curl -X POST http://192.168.0.190:8080/api/sweep/a/start
```

### `POST /api/sweep/{id}/stop`
Stop sweep execution immediately. The PSU voltage is held at its last-programmed setpoint.

```json
{}
```
```bash
curl -X POST http://192.168.0.190:8080/api/sweep/a/stop
```

---

## Datalogger Endpoints

The datalogger records V/I/P samples from a PSU at a configurable interval. Samples are held in a ring buffer (max 10,000 per channel); when full, the oldest sample is discarded. Logging state (enabled/disabled) survives a `clear` operation.

### `GET /api/datalog`
Logging status for all PSUs (no sample data).

**Response:**
```json
{
  "a": { "enabled": true,  "interval_ms": 500, "samples": 247 },
  "b": { "enabled": false, "interval_ms": 500, "samples": 0   }
}
```

### `GET /api/datalog/{id}`
All logged samples plus status for a single PSU.

**Response:**
```json
{
  "status": { "enabled": true, "interval_ms": 500, "samples": 3 },
  "samples": [
    { "t": 0,    "v": 12.48, "i": 0.312, "p": 3.89 },
    { "t": 500,  "v": 12.47, "i": 0.315, "p": 3.93 },
    { "t": 1000, "v": 12.48, "i": 0.310, "p": 3.87 }
  ]
}
```

`t`: milliseconds since first sample in this log session.
`v`: output voltage (V).
`i`: output current (A).
`p`: output power (W).

```bash
curl http://192.168.0.190:8080/api/datalog/a
```

### `GET /api/datalog/{id}/csv`
Download logged samples as a CSV file. The response has `Content-Disposition: attachment; filename=psu_{id}_log.csv`.

**CSV columns:** `time_ms, voltage_V, current_A, power_W`

```
time_ms,voltage_V,current_A,power_W
0,12.48,0.312,3.89
500,12.47,0.315,3.93
1000,12.48,0.310,3.87
```

```bash
curl -o psu_a_log.csv http://192.168.0.190:8080/api/datalog/a/csv
```

### `POST /api/datalog/{id}/start`
Start logging. If logging is already active, the interval is updated. Minimum `interval_ms` is 100; default is 500.

```json
{ "interval_ms": 500 }
```
```bash
curl -X POST -H 'Content-Type: application/json' \
     -d '{"interval_ms":200}' \
     http://192.168.0.190:8080/api/datalog/a/start
```

### `POST /api/datalog/{id}/stop`
Stop logging. The sample buffer is preserved.

```json
{}
```

### `POST /api/datalog/{id}/clear`
Clear all samples from the buffer. Does not affect the logging state (if logging is running, it continues after the clear).

```json
{}
```

---

## Notes

- **Rate limiting:** There is no enforced rate limit. Polling `/api/psu/{id}/readings` faster than the PSU polling cycle (~200 ms) returns cached data; you will not get newer values by polling faster.
- **Polling the sweep status:** While a sweep is running, poll `GET /api/sweep/{id}` at ~500 ms to track `elapsed_ms` and `current_step`. The sweep ends when `running` becomes `false`.
- **Concurrent sweeps:** Both PSU channels support independent simultaneous sweep execution.
- **Concurrent datalogger and sweep:** The datalogger and sweep can run simultaneously on the same PSU channel.

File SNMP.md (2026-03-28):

# SNMP Reference

The PSU controller includes a built-in SNMPv2c agent. This document describes the OID structure, data types, scaling, and command examples.

---

## Agent Configuration

| Parameter | Value |
|---|---|
| Protocol | SNMPv2c |
| Transport | UDP |
| Port | 161 |
| Read community | `public` |
| Write community | `private` |
| Base OID | `1.3.6.1.4.1.99999.1` |
| Operations | GET, GETNEXT, GETBULK, SET |

---

## OID Structure

```
1.3.6.1.4.1.99999.1
│
├── .1.0          ─ Scalar: psuCount
│
└── .2.1.{col}.{row}   ─ PSU Table
         │       │
         │       └── Row: 1 = PSU-A,  2 = PSU-B
         └────────── Column: 1–28 (see table below)
```

---

## Scalar OIDs

| OID | Name | Type | Description |
|---|---|---|---|
| `...1.0` | `psuCount` | INTEGER | Number of connected PSU channels |

```bash
snmpget -v2c -c public 192.168.0.190 1.3.6.1.4.1.99999.1.1.0
```

---

## PSU Table OIDs

OID format: `1.3.6.1.4.1.99999.1.2.1.{column}.{row}`

Row 1 = PSU-A, Row 2 = PSU-B.

All integer values are raw register values. Divide by the **Divisor** to obtain engineering units. For example, a raw voltage value of `1250` with divisor 100 represents **12.50 V**.

To write a value, multiply the desired engineering value by the divisor and send as an INTEGER. For example, to set 5.00 V: `5.00 × 100 = 500`.

| Col | OID Suffix | Name | Type | Divisor | Units | Access | Description |
|---|---|---|---|---|---|---|---|
| 1 | `.2.1.1.{r}` | `psuIndex` | INTEGER | — | — | RO | Row index (1, 2, …) |
| 2 | `.2.1.2.{r}` | `psuName` | STRING | — | — | RO | Channel name (PSU-A, PSU-B) |
| 3 | `.2.1.3.{r}` | `psuSetVoltage` | INTEGER | 100 | V | **RW** | Voltage setpoint |
| 4 | `.2.1.4.{r}` | `psuSetCurrent` | INTEGER | 1000 | A | **RW** | Current limit |
| 5 | `.2.1.5.{r}` | `psuOutputVoltage` | INTEGER | 100 | V | RO | Measured output voltage |
| 6 | `.2.1.6.{r}` | `psuOutputCurrent` | INTEGER | 1000 | A | RO | Measured output current |
| 7 | `.2.1.7.{r}` | `psuOutputPower` | INTEGER | 100 | W | RO | Calculated output power |
| 8 | `.2.1.8.{r}` | `psuInputVoltage` | INTEGER | 100 | V | RO | DC input bus voltage |
| 9 | `.2.1.9.{r}` | `psuInternalTemp` | INTEGER | 10 | °C | RO | Internal temperature sensor |
| 10 | `.2.1.10.{r}` | `psuExternalTemp` | INTEGER | 10 | °C | RO | External temperature sensor (−10 = not present) |
| 11 | `.2.1.11.{r}` | `psuOutputEnabled` | INTEGER | — | 0/1 | **RW** | 1 = output ON, 0 = output OFF |
| 12 | `.2.1.12.{r}` | `psuCVCC` | INTEGER | — | 0/1 | RO | 0 = CV mode, 1 = CC mode |
| 13 | `.2.1.13.{r}` | `psuProtectStatus` | INTEGER | — | bitmask | RO | Protection status register (0 = no event) |
| 14 | `.2.1.14.{r}` | `psuKeyLock` | INTEGER | — | 0/1 | **RW** | 1 = front panel keys locked |
| 15 | `.2.1.15.{r}` | `psuBacklight` | INTEGER | — | 0–5 | **RW** | LCD backlight level |
| 16 | `.2.1.16.{r}` | `psuBeeper` | INTEGER | — | 0/1 | **RW** | 1 = key beeper enabled |
| 17 | `.2.1.17.{r}` | `psuModel` | STRING | — | — | RO | Device model string |
| 18 | `.2.1.18.{r}` | `psuFirmware` | STRING | — | — | RO | Firmware version |
| 19 | `.2.1.19.{r}` | `psuAmpHours` | Counter32 | — | mAh | RO | Accumulated amp-hours |
| 20 | `.2.1.20.{r}` | `psuWattHours` | Counter32 | — | mWh | RO | Accumulated watt-hours |
| 21 | `.2.1.21.{r}` | `psuOutputTimeSec` | Counter32 | — | s | RO | Total output ON time |
| 22 | `.2.1.22.{r}` | `psuMPPTEnabled` | INTEGER | — | 0/1 | **RW** | 1 = MPPT solar mode ON |
| 23 | `.2.1.23.{r}` | `psuSleepMin` | INTEGER | — | min | **RW** | Auto-sleep timeout (0 = disabled) |
| 24 | `.2.1.24.{r}` | `psuOVP` | INTEGER | 100 | V | **RW** | Over-voltage protection threshold |
| 25 | `.2.1.25.{r}` | `psuOCP` | INTEGER | 1000 | A | **RW** | Over-current protection threshold |
| 26 | `.2.1.26.{r}` | `psuOPP` | INTEGER | 10 | W | **RW** | Over-power protection threshold |
| 27 | `.2.1.27.{r}` | `psuOTP` | INTEGER | 10 | °C | **RW** | Over-temperature protection threshold |
| 28 | `.2.1.28.{r}` | `psuLVP` | INTEGER | 100 | V | **RW** | Low-voltage (input) protection threshold |

---

## Value Scaling

Integer OIDs store values as scaled integers to avoid floating-point in the base SNMP protocol.

**Reading:** `engineering_value = raw_integer / divisor`

| Raw value | Divisor | Result |
|---|---|---|
| 1250 | 100 | 12.50 V |
| 2000 | 1000 | 2.000 A |
| 3890 | 100 | 38.90 W |
| 318 | 10 | 31.8 °C |

**Writing:** `raw_integer = round(engineering_value × divisor)`

| Desired | Divisor | Raw to send |
|---|---|---|
| 5.00 V | 100 | 500 |
| 3.300 A | 1000 | 3300 |
| 62.0 V (OVP) | 100 | 6200 |
| 80.0 °C (OTP) | 10 | 800 |

---

## Command Reference

Replace `192.168.0.190` with your device IP. For PSU-B substitute row `2` for `1`.

### Read Operations

```bash
# Scalar: number of channels
snmpget -v2c -c public 192.168.0.190 1.3.6.1.4.1.99999.1.1.0

# Walk all PSU table entries (both channels, all columns)
snmpwalk -v2c -c public 192.168.0.190 1.3.6.1.4.1.99999.1.2

# Bulk-get all 28 columns for PSU-A in a single UDP packet
snmpbulkget -v2c -c public -Cr28 192.168.0.190 1.3.6.1.4.1.99999.1.2.1.0.1

# Individual reads — PSU-A (row 1)
snmpget -v2c -c public 192.168.0.190 1.3.6.1.4.1.99999.1.2.1.1.1   # psuIndex
snmpget -v2c -c public 192.168.0.190 1.3.6.1.4.1.99999.1.2.1.2.1   # psuName
snmpget -v2c -c public 192.168.0.190 1.3.6.1.4.1.99999.1.2.1.3.1   # psuSetVoltage  (raw ÷100 → V)
snmpget -v2c -c public 192.168.0.190 1.3.6.1.4.1.99999.1.2.1.4.1   # psuSetCurrent  (raw ÷1000 → A)
snmpget -v2c -c public 192.168.0.190 1.3.6.1.4.1.99999.1.2.1.5.1   # psuOutputVoltage
snmpget -v2c -c public 192.168.0.190 1.3.6.1.4.1.99999.1.2.1.6.1   # psuOutputCurrent
snmpget -v2c -c public 192.168.0.190 1.3.6.1.4.1.99999.1.2.1.7.1   # psuOutputPower
snmpget -v2c -c public 192.168.0.190 1.3.6.1.4.1.99999.1.2.1.8.1   # psuInputVoltage
snmpget -v2c -c public 192.168.0.190 1.3.6.1.4.1.99999.1.2.1.9.1   # psuInternalTemp  (raw ÷10 → °C)
snmpget -v2c -c public 192.168.0.190 1.3.6.1.4.1.99999.1.2.1.10.1  # psuExternalTemp
snmpget -v2c -c public 192.168.0.190 1.3.6.1.4.1.99999.1.2.1.11.1  # psuOutputEnabled (0/1)
snmpget -v2c -c public 192.168.0.190 1.3.6.1.4.1.99999.1.2.1.12.1  # psuCVCC (0=CV, 1=CC)
snmpget -v2c -c public 192.168.0.190 1.3.6.1.4.1.99999.1.2.1.13.1  # psuProtectStatus
snmpget -v2c -c public 192.168.0.190 1.3.6.1.4.1.99999.1.2.1.14.1  # psuKeyLock
snmpget -v2c -c public 192.168.0.190 1.3.6.1.4.1.99999.1.2.1.15.1  # psuBacklight (0-5)
snmpget -v2c -c public 192.168.0.190 1.3.6.1.4.1.99999.1.2.1.16.1  # psuBeeper (0/1)
snmpget -v2c -c public 192.168.0.190 1.3.6.1.4.1.99999.1.2.1.17.1  # psuModel
snmpget -v2c -c public 192.168.0.190 1.3.6.1.4.1.99999.1.2.1.18.1  # psuFirmware
snmpget -v2c -c public 192.168.0.190 1.3.6.1.4.1.99999.1.2.1.19.1  # psuAmpHours (mAh)
snmpget -v2c -c public 192.168.0.190 1.3.6.1.4.1.99999.1.2.1.20.1  # psuWattHours (mWh)
snmpget -v2c -c public 192.168.0.190 1.3.6.1.4.1.99999.1.2.1.21.1  # psuOutputTimeSec
snmpget -v2c -c public 192.168.0.190 1.3.6.1.4.1.99999.1.2.1.22.1  # psuMPPTEnabled
snmpget -v2c -c public 192.168.0.190 1.3.6.1.4.1.99999.1.2.1.23.1  # psuSleepMin
snmpget -v2c -c public 192.168.0.190 1.3.6.1.4.1.99999.1.2.1.24.1  # psuOVP  (raw ÷100 → V)
snmpget -v2c -c public 192.168.0.190 1.3.6.1.4.1.99999.1.2.1.25.1  # psuOCP  (raw ÷1000 → A)
snmpget -v2c -c public 192.168.0.190 1.3.6.1.4.1.99999.1.2.1.26.1  # psuOPP  (raw ÷10 → W)
snmpget -v2c -c public 192.168.0.190 1.3.6.1.4.1.99999.1.2.1.27.1  # psuOTP  (raw ÷10 → °C)
snmpget -v2c -c public 192.168.0.190 1.3.6.1.4.1.99999.1.2.1.28.1  # psuLVP  (raw ÷100 → V)
```

### Write Operations

```bash
# Set PSU-A voltage to 12.50 V  (12.50 × 100 = 1250)
snmpset -v2c -c private 192.168.0.190 1.3.6.1.4.1.99999.1.2.1.3.1 i 1250

# Set PSU-B voltage to 5.00 V
snmpset -v2c -c private 192.168.0.190 1.3.6.1.4.1.99999.1.2.1.3.2 i 500

# Set PSU-A current limit to 2.000 A  (2.000 × 1000 = 2000)
snmpset -v2c -c private 192.168.0.190 1.3.6.1.4.1.99999.1.2.1.4.1 i 2000

# Turn PSU-A output ON
snmpset -v2c -c private 192.168.0.190 1.3.6.1.4.1.99999.1.2.1.11.1 i 1

# Turn PSU-B output OFF
snmpset -v2c -c private 192.168.0.190 1.3.6.1.4.1.99999.1.2.1.11.2 i 0

# Lock PSU-A front panel
snmpset -v2c -c private 192.168.0.190 1.3.6.1.4.1.99999.1.2.1.14.1 i 1

# Set PSU-A backlight to level 2
snmpset -v2c -c private 192.168.0.190 1.3.6.1.4.1.99999.1.2.1.15.1 i 2

# Set PSU-A OVP to 62.00 V  (62.00 × 100 = 6200)
snmpset -v2c -c private 192.168.0.190 1.3.6.1.4.1.99999.1.2.1.24.1 i 6200

# Set PSU-A OCP to 6.100 A  (6.100 × 1000 = 6100)
snmpset -v2c -c private 192.168.0.190 1.3.6.1.4.1.99999.1.2.1.25.1 i 6100
```

---

## Monitoring Integration

### Zabbix

Add the PSU controller as a host with SNMPv2 interface, community `public`, port 161.

Example item configuration for PSU-A output voltage:
- **OID:** `1.3.6.1.4.1.99999.1.2.1.5.1`
- **Type:** SNMPv2 agent
- **Value type:** Numeric (float)
- **Preprocessing:** Multiply by `0.01` (divisor 100)
- **Units:** V

Recommended trigger for protection event:
- `{HOST:1.3.6.1.4.1.99999.1.2.1.13.1.last()} <> 0` → PROBLEM

### LibreNMS / Nagios

Use the OID table to build custom checks or templates. `snmpwalk` the base OID to discover all values automatically:

```bash
snmpwalk -v2c -c public 192.168.0.190 1.3.6.1.4.1.99999.1
```

### Python (pysnmp)

```python
from pysnmp.hlapi import *

B = '1.3.6.1.4.1.99999.1'

# Read PSU-A output voltage
for (errorIndication, errorStatus, errorIndex, varBinds) in getCmd(
        SnmpEngine(),
        CommunityData('public', mpModel=1),
        UdpTransportTarget(('192.168.0.190', 161)),
        ContextData(),
        ObjectType(ObjectIdentity(B + '.2.1.5.1'))):
    if not errorIndication and not errorStatus:
        raw = int(varBinds[0][1])
        print(f'PSU-A output voltage: {raw / 100:.2f} V')
```

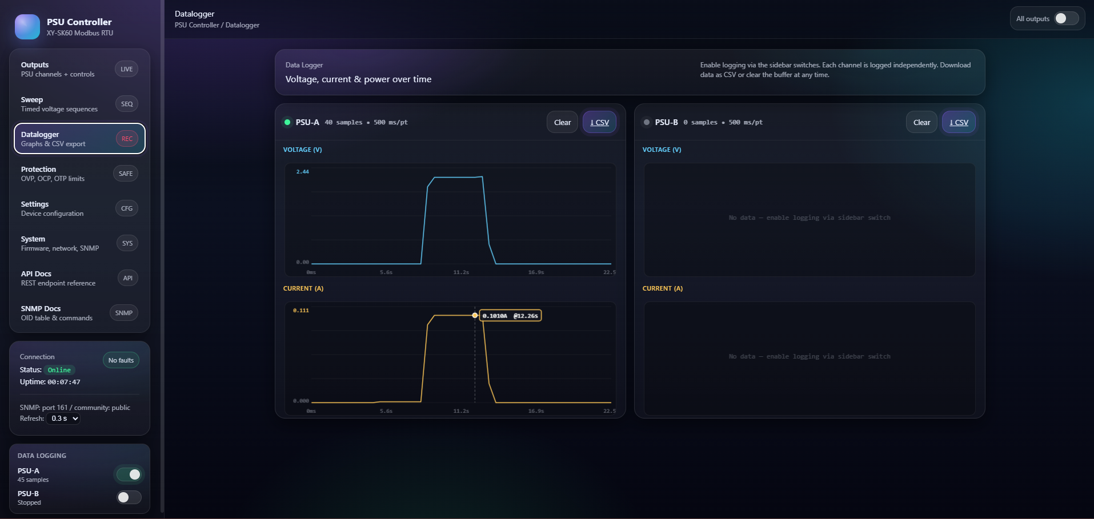
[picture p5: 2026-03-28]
img/WEB-UI_Datalogger.png

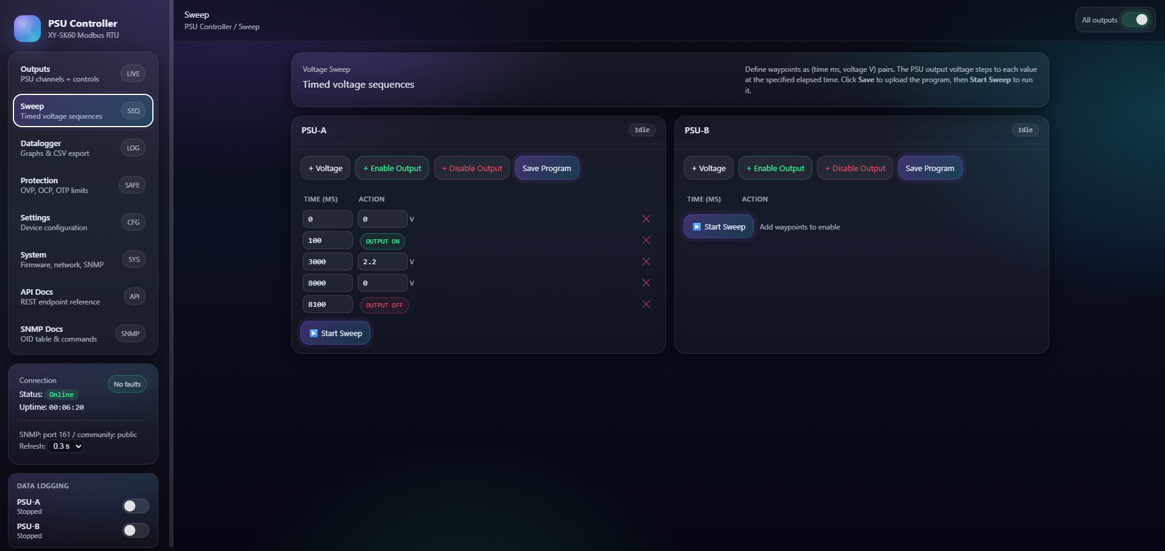
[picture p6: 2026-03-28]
img/WEB-UI_Sweep.png

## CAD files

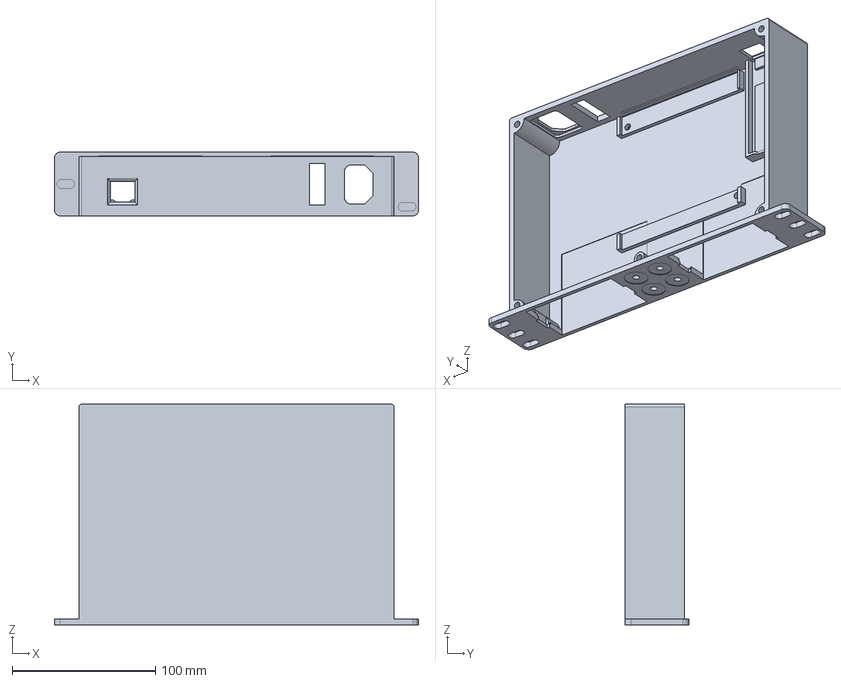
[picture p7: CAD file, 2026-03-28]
3D files/Dual-PSU-Body.step
254.0 x 44.5 x 154.0 mm

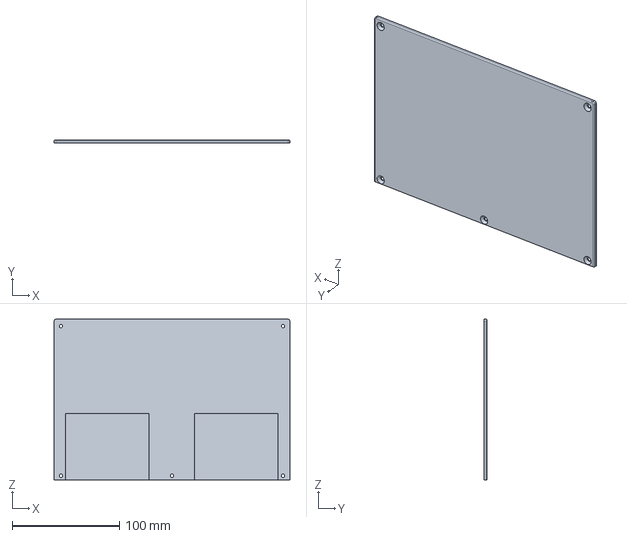
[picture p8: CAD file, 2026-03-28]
3D files/Dual-PSU-Lid.step
220.0 x 2.85 x 149.9 mm

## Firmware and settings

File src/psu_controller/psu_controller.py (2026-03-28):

#!/usr/bin/env python3
"""
PSU Controller - Main entry point.
Starts web server and SNMP agent for XY-SK60 buck-boost converter control.
"""

import json
import os
import sys
import threading

from modbus_psu import ModbusPSU
from web_server import start_web_server
import web_server
from snmp_agent import start_snmp_agent
from sweep_manager import SweepManager
from datalogger import DataLogger

BASE_DIR = os.path.dirname(os.path.abspath(__file__))


def load_config():
    config_path = os.path.join(BASE_DIR, 'config.json')
    if not os.path.isfile(config_path):
        print('[ERROR] config.json not found at %s' % config_path)
        sys.exit(1)
    with open(config_path, 'r') as f:
        return json.load(f)


def main():
    config = load_config()

    # Initialize PSU connections
    psus = {}
    for psu_id, psu_cfg in config['psus'].items():
        print('[INIT] Connecting to %s on %s at %d baud...' % (
            psu_cfg['name'], psu_cfg['port'], psu_cfg['baudrate']))
        psu = ModbusPSU(
            port=psu_cfg['port'],
            baudrate=psu_cfg['baudrate'],
            address=psu_cfg['address'],
            name=psu_cfg['name'],
        )
        if psu.connected:
            print('[INIT] %s connected OK' % psu_cfg['name'])
        else:
            print('[INIT] WARNING: %s failed to connect on %s' % (
                psu_cfg['name'], psu_cfg['port']))
        psus[psu_id] = psu

    # Quick connectivity test
    for psu_id, psu in psus.items():
        readings = psu.get_readings()
        if readings:
            print('[INIT] %s: Vin=%.2fV, Vset=%.2fV, Iset=%.3fA, Output=%s' % (
                psu.name,
                readings['v_in'],
                readings['v_set'],
                readings['i_set'],
                'ON' if readings['output_on'] else 'OFF',
            ))
        else:
            print('[INIT] %s: No response from device' % psu.name)

    web_cfg = config.get('web', {})
    snmp_cfg = config.get('snmp', {})

    # Initialize sweep manager and datalogger
    sweep_mgr = SweepManager()
    sweep_mgr.set_psus(psus)

    data_logger = DataLogger()
    data_logger.set_psus(psus)

    print('[INIT] Sweep manager and datalogger ready')

    # Set PSU references in web server module
    web_server.psus = psus

    # Start SNMP agent in background thread
    snmp_thread = threading.Thread(
        target=start_snmp_agent,
        args=(psus,),
        kwargs={
            'community': snmp_cfg.get('community', 'public'),
            'write_community': snmp_cfg.get('write_community', 'private'),
            'host': snmp_cfg.get('host', '0.0.0.0'),
            'port': snmp_cfg.get('port', 161),
        },
        daemon=True,
    )
    snmp_thread.start()

    # Start web server (blocking, main thread)
    print('[INIT] Starting PSU Controller')
    print('[INIT] Web UI: http://0.0.0.0:%d/' % web_cfg.get('port', 8080))
    print('[INIT] SNMP:   %s:%d community=%s' % (
        snmp_cfg.get('host', '0.0.0.0'),
        snmp_cfg.get('port', 161),
        snmp_cfg.get('community', 'public'),
    ))

    try:
        start_web_server(
            host=web_cfg.get('host', '0.0.0.0'),
            port=web_cfg.get('port', 8080),
            sweep_mgr=sweep_mgr,
            data_logger=data_logger,
        )
    except KeyboardInterrupt:
        print('\n[SHUTDOWN] Stopping...')
    finally:
        for psu in psus.values():
            psu.close()
        print('[SHUTDOWN] Done.')


if __name__ == '__main__':
    main()

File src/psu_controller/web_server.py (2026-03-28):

import json
import os
import threading
from http.server import HTTPServer, BaseHTTPRequestHandler
from socketserver import ThreadingMixIn

# Will be set by psu_controller.py before starting
psus = {}
sweep_manager = None
datalogger = None
BASE_DIR = os.path.dirname(os.path.abspath(__file__))
WEB_DIR = os.path.join(BASE_DIR, 'web')

MIME_TYPES = {
    '.html': 'text/html',
    '.css': 'text/css',
    '.js': 'application/javascript',
    '.json': 'application/json',
    '.png': 'image/png',
    '.ico': 'image/x-icon',
}


class PSURequestHandler(BaseHTTPRequestHandler):

    def log_message(self, format, *args):
        pass  # suppress default logging

    def _send_csv(self, csv_data, filename='data.csv'):
        body = csv_data.encode('utf-8')
        self.send_response(200)
        self.send_header('Content-Type', 'text/csv')
        self.send_header('Content-Disposition', 'attachment; filename="%s"' % filename)
        self.send_header('Content-Length', str(len(body)))
        self.send_header('Access-Control-Allow-Origin', '*')
        self.end_headers()
        self.wfile.write(body)

    def _send_json(self, data, status=200):
        body = json.dumps(data, indent=None, separators=(',', ':')).encode('ascii')
        self.send_response(status)
        self.send_header('Content-Type', 'application/json')
        self.send_header('Content-Length', str(len(body)))
        self.send_header('Access-Control-Allow-Origin', '*')
        self.end_headers()
        self.wfile.write(body)

    def _send_error_json(self, status, message):
        self._send_json({'error': message}, status)

    def _read_body(self):
        length = int(self.headers.get('Content-Length', 0))
        if length == 0:
            return {}
        raw = self.rfile.read(length)
        try:
            return json.loads(raw)
        except Exception:
            return {}

    def _serve_file(self, path):
        full_path = os.path.join(WEB_DIR, path.lstrip('/'))
        full_path = os.path.normpath(full_path)
        if not full_path.startswith(os.path.normpath(WEB_DIR)):
            self.send_error(403)
            return
        if not os.path.isfile(full_path):
            self.send_error(404)
            return
        ext = os.path.splitext(full_path)[1]
        mime = MIME_TYPES.get(ext, 'application/octet-stream')
        with open(full_path, 'rb') as f:
            data = f.read()
        self.send_response(200)
        self.send_header('Content-Type', mime)
        self.send_header('Content-Length', str(len(data)))
        self.end_headers()
        self.wfile.write(data)

    def _get_psu(self, psu_id):
        psu_id = psu_id.lower()
        if psu_id in psus:
            return psus[psu_id]
        return None

    # --- GET routes ---

    def do_GET(self):
        path = self.path.split('?')[0]

        if path == '/' or path == '/index.html':
            self._serve_file('index.html')
        elif path.startswith('/api/'):
            self._route_api_get(path)
        elif path.startswith('/'):
            self._serve_file(path)
        else:
            self.send_error(404)

    def _route_api_get(self, path):
        if path == '/api/status':
            result = {}
            for psu_id, psu in psus.items():
                result[psu_id] = psu.get_full_status()
            self._send_json(result)

        elif path == '/api/readings':
            result = {}
            for psu_id, psu in psus.items():
                r = psu.get_readings_cached()
                if r:
                    r['name'] = psu.name
                result[psu_id] = r or {}
            self._send_json(result)

        elif path.startswith('/api/psu/'):
            parts = path.split('/')
            if len(parts) >= 4:
                psu_id = parts[3]
                psu = self._get_psu(psu_id)
                if psu is None:
                    self._send_error_json(404, 'PSU not found')
                    return
                if len(parts) == 4 or (len(parts) == 5 and parts[4] == ''):
                    self._send_json(psu.get_full_status())
                elif len(parts) == 5 and parts[4] == 'readings':
                    r = psu.get_readings()
                    self._send_json(r if r else {'error': 'read failed'})
                elif len(parts) == 5 and parts[4] == 'settings':
                    s = psu.get_settings()
                    self._send_json(s if s else {'error': 'read failed'})
                elif len(parts) == 5 and parts[4] == 'protection':
                    p = psu.get_protection()
                    self._send_json(p if p else {'error': 'read failed'})
                else:
                    self._send_error_json(404, 'Unknown endpoint')
            else:
                self._send_error_json(404, 'Unknown endpoint')

        elif path == '/api/snmp':
            self._send_json({
                'community': 'public',
                'write_community': 'private',
                'port': 161,
                'base_oid': '1.3.6.1.4.1.99999.1',
            })

        elif path == '/api/sweep':
            if sweep_manager:
                self._send_json(sweep_manager.get_status())
            else:
                self._send_error_json(503, 'Sweep manager not available')

        elif path.startswith('/api/sweep/'):
            parts = path.split('/')
            if len(parts) >= 4:
                psu_id = parts[3]
                if sweep_manager:
                    self._send_json(sweep_manager.get_status(psu_id))
                else:
                    self._send_error_json(503, 'Sweep manager not available')
            else:
                self._send_error_json(400, 'Missing PSU id')

        elif path == '/api/datalog':
            if datalogger:
                self._send_json(datalogger.get_all_status())
            else:
                self._send_error_json(503, 'Datalogger not available')

        elif path.startswith('/api/datalog/'):
            parts = path.split('/')
            if len(parts) >= 4:
                psu_id = parts[3]
                sub = parts[4] if len(parts) >= 5 else ''
                if not datalogger:
                    self._send_error_json(503, 'Datalogger not available')
                    return
                if sub == 'csv':
                    csv_data, err = datalogger.get_csv(psu_id)
                    if err:
                        self._send_error_json(404, err)
                    else:
                        self._send_csv(csv_data, 'psu_%s_log.csv' % psu_id)
                else:
                    result, err = datalogger.get_data(psu_id)
                    if err:
                        self._send_error_json(404, err)
                    else:
                        self._send_json(result)
            else:
                self._send_error_json(400, 'Missing PSU id')

        else:
            self._send_error_json(404, 'Unknown API endpoint')

    # --- POST routes ---
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

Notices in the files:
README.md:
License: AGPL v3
